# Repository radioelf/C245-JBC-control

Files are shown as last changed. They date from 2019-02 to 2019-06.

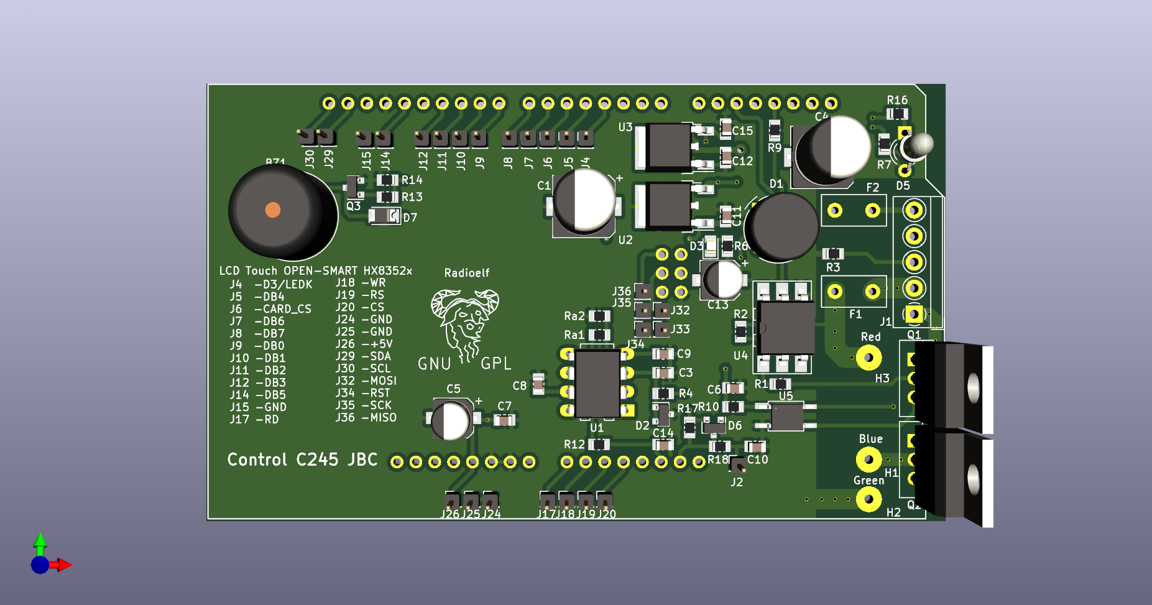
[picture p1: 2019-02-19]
cad/JBC_C245/jbc_245.png

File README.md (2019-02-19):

# C245 JBC control

 Harware y sofware para el control de soldadores JBC con puntas del tipo C245
 el  harware se ha realizado con KiCad y el sofware para un Arduino Mega.

Creative Commons License Disclaimer

UNLESS OTHERWISE MUTUALLY AGREED TO BY THE PARTIES IN WRITING, LICENSOR OFFERS THE WORK AS-IS AND MAKES NO REPRESENTATIONS OR WARRANTIES OF ANY KIND CONCERNING THE WORK, EXPRESS, IMPLIED, STATUTORY OR OTHERWISE, INCLUDING, WITHOUT LIMITATION, WARRANTIES OF TITLE, MERCHANTIBILITY, FITNESS FOR A PARTICULAR PURPOSE, NONINFRINGEMENT, OR THE ABSENCE OF LATENT OR OTHER DEFECTS, ACCURACY, OR THE PRESENCE OF ABSENCE OF ERRORS, WHETHER OR NOT DISCOVERABLE. SOME JURISDICTIONS DO NOT ALLOW THE EXCLUSION OF IMPLIED WARRANTIES, SO SUCH EXCLUSION MAY NOT APPLY TO YOU. EXCEPT TO THE EXTENT REQUIRED BY APPLICABLE LAW, IN NO EVENT WILL LICENSOR BE LIABLE TO YOU ON ANY LEGAL THEORY FOR ANY SPECIAL, INCIDENTAL, CONSEQUENTIAL, PUNITIVE OR EXEMPLARY DAMAGES ARISING OUT OF THIS LICENSE OR THE USE OF THE WORK, EVEN IF LICENSOR HAS BEEN ADVISED OF THE POSSIBILITY OF SUCH DAMAGES.

http://creativecommons.org/licenses/by-sa/3.0/

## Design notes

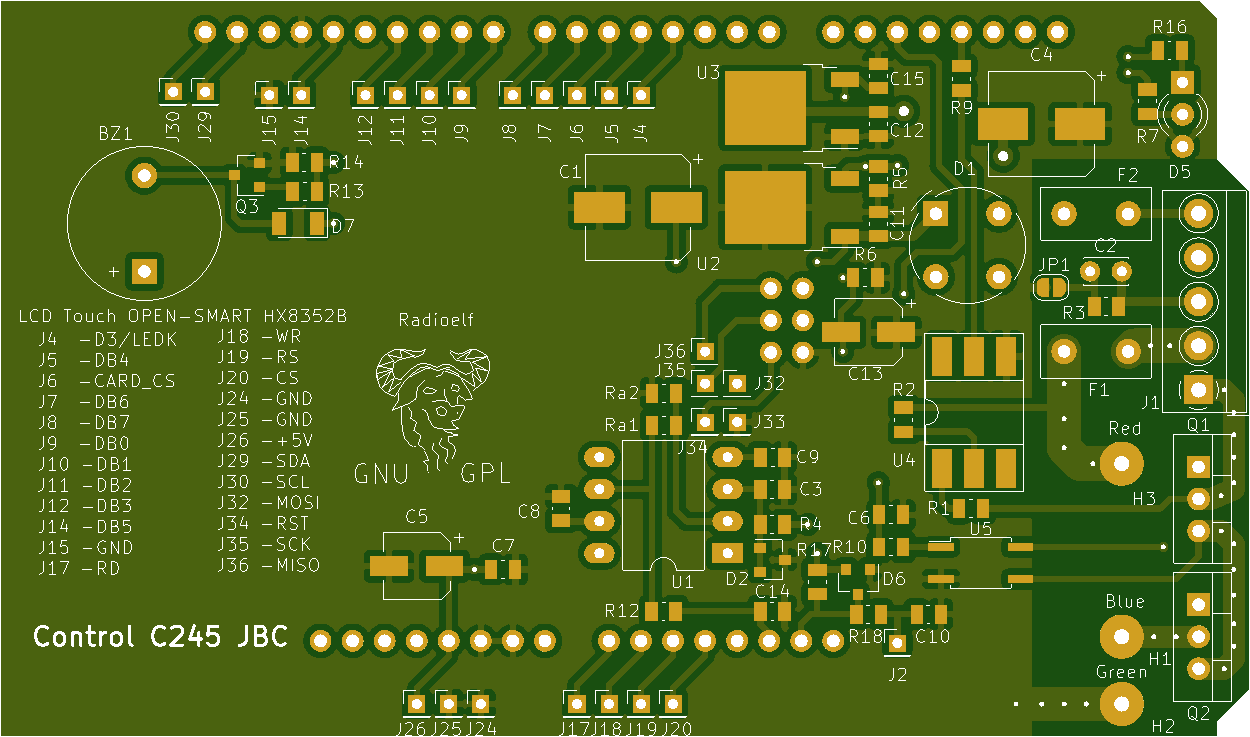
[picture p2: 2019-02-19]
cad/JBC_C245/c05b7eac-661d-4eba-980e-21c51f4449f4_1_0_1.png

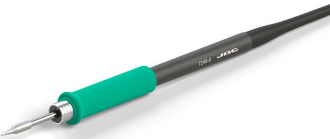
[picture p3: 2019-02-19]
sof/imagenes/jbc.png

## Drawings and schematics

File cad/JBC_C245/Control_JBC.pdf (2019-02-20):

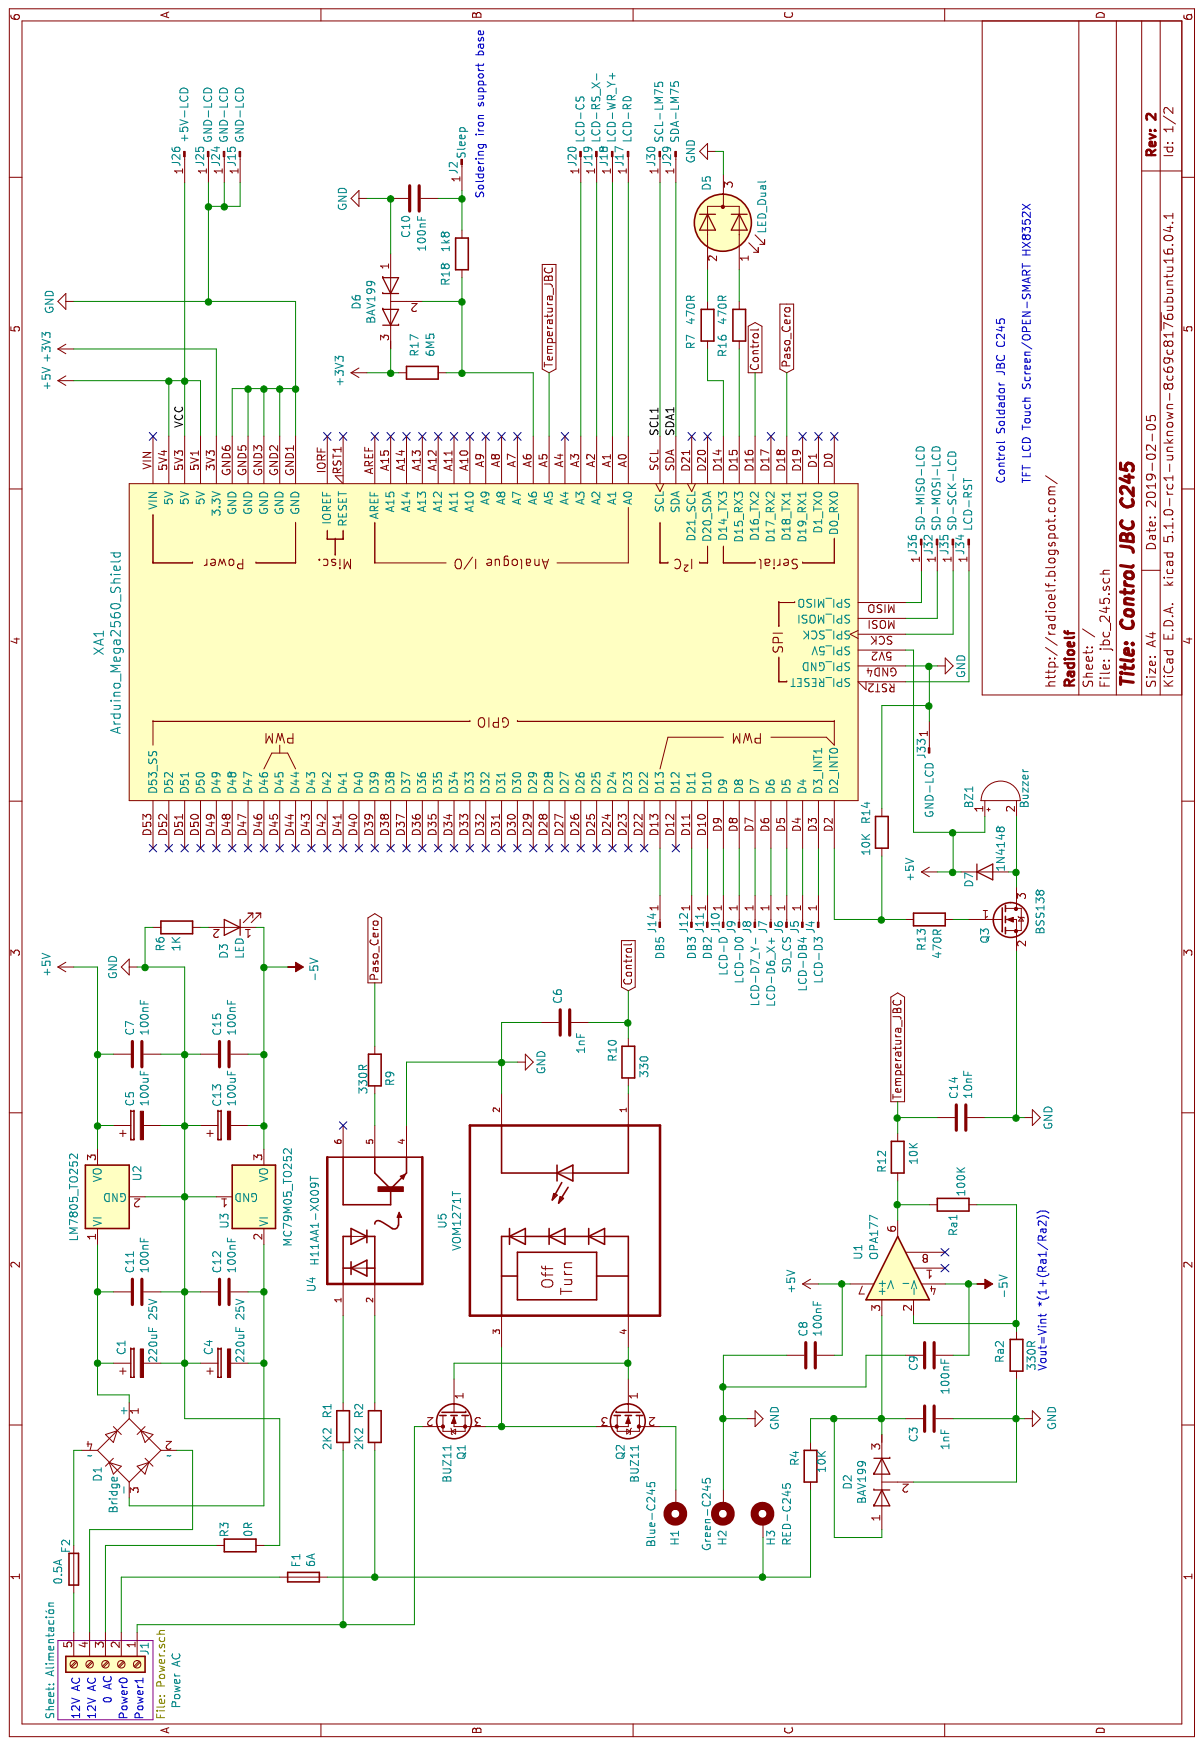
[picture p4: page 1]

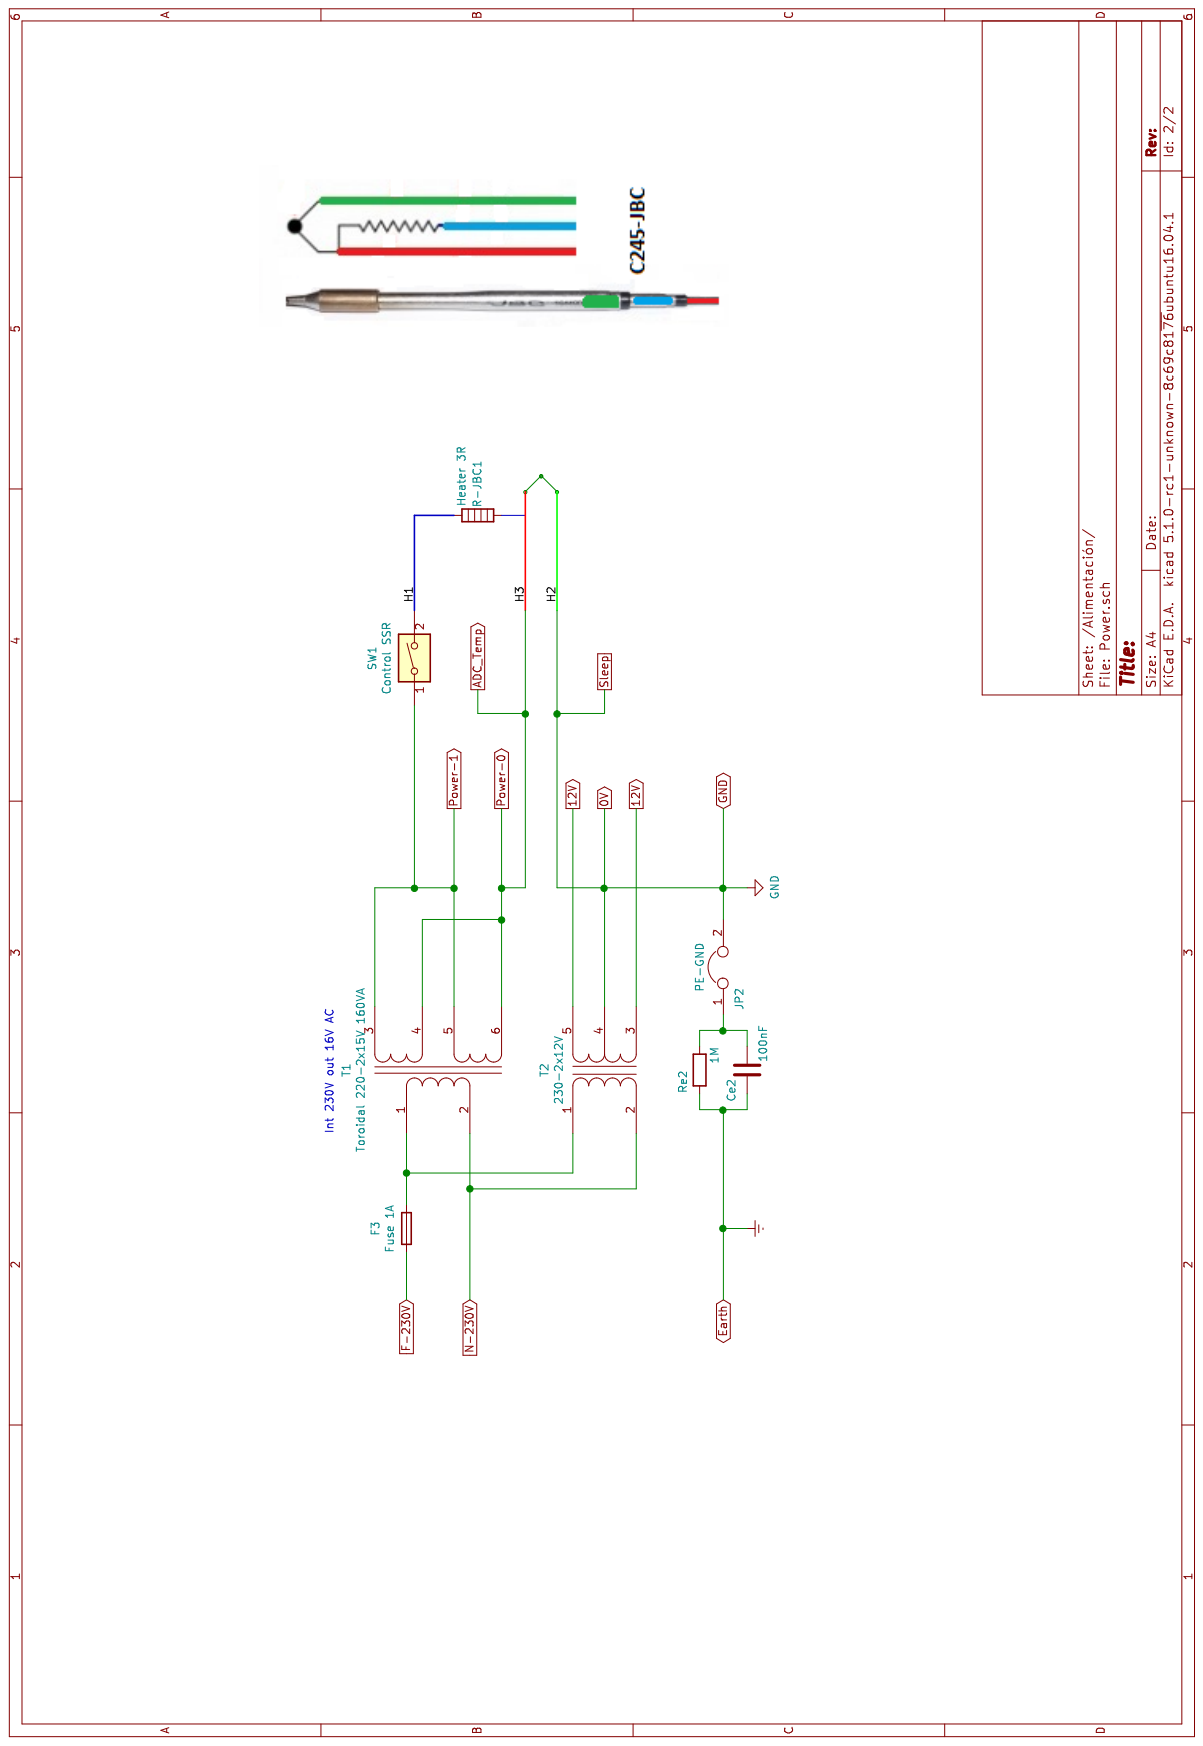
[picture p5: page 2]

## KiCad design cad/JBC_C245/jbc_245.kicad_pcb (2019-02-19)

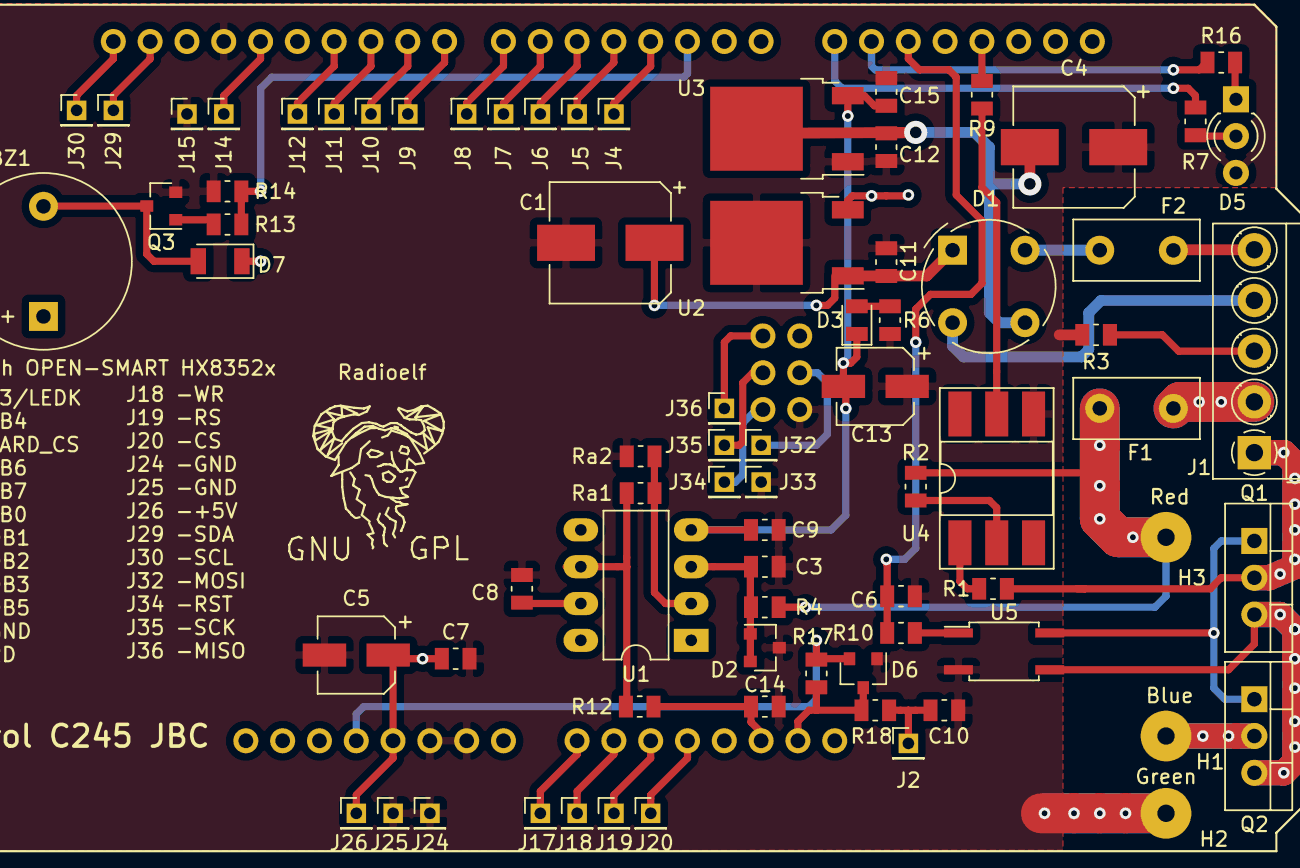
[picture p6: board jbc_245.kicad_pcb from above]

Board: 2 copper layers, 79 parts (0 on the bottom side), 54 nets.

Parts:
BZ1: Buzzer; Buzzer_12x9.5RM7.6
C1, C4: 220uF 25V; CP_Elec_8x10
C3, C6: 1nF; C_0805_2012Metric
C5, C13: 100uF; CP_Elec_5x4.5
C7, C8, C9, C10, C11, C12, C15: 100nF; C_0805_2012Metric
C14: 10nF; C_0805_2012Metric
D1: Bridge; Diode_Bridge_Round_D9.0mm
D2, D6: BAV199; D_SOT-23_BAV199
D3: LED; LED_0805_2012Metric
D5: LED_Dual; LED_D3.0mm-3
D7: 1N4148; D_1206_3216Metric
F1: 6A; Fuse_Littlefuse_395Series
F2: 0.5A; Fuse_Littlefuse_395Series
H1: Blue-C245; SolderWirePad_single_1-2mmDrill
H2: Green-C245; SolderWirePad_single_1-2mmDrill
H3: RED-C245; SolderWirePad_single_1-2mmDrill
J1: Power AC; TerminalBlock_MetzConnect_Type059_RT06305HBWC_1x05_P3.50mm_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
J2: Sleep; PinHeader_1x01_P2.00mm_Vertical
J4: LCD-D3; PinHeader_1x01_P2.00mm_Vertical
J5: LCD-DB4; PinHeader_1x01_P2.00mm_Vertical
J6: SD_CS; PinHeader_1x01_P2.00mm_Vertical
J7: LCD-D6_X+; PinHeader_1x01_P2.00mm_Vertical
J8: LCD-D7_Y-; PinHeader_1x01_P2.00mm_Vertical
J9: LCD-D0; PinHeader_1x01_P2.00mm_Vertical
J10: LCD-D; PinHeader_1x01_P2.00mm_Vertical
J11: DB2; PinHeader_1x01_P2.00mm_Vertical
J12: DB3; PinHeader_1x01_P2.00mm_Vertical
J14: DB5; PinHeader_1x01_P2.00mm_Vertical
J15, J24, J25, J33: GND-LCD; PinHeader_1x01_P2.00mm_Vertical
J17: LCD-RD; PinHeader_1x01_P2.00mm_Vertical
J18: LCD-WR_Y+; PinHeader_1x01_P2.00mm_Vertical
J19: LCD-RS_X-; PinHeader_1x01_P2.00mm_Vertical
J20: LCD-CS; PinHeader_1x01_P2.00mm_Vertical
J26: +5V-LCD; PinHeader_1x01_P2.00mm_Vertical
J29: SDA-LM75; PinHeader_1x01_P2.00mm_Vertical
J30: SCL-LM75; PinHeader_1x01_P2.00mm_Vertical
J32: SD-MOSI-LCD; PinHeader_1x01_P2.00mm_Vertical
J34: LCD-RST; PinHeader_1x01_P2.00mm_Vertical
J35: SD-SCK-LCD; PinHeader_1x01_P2.00mm_Vertical
J36: SD-MISO-LCD; PinHeader_1x01_P2.00mm_Vertical
Q1, Q2: BUZ11; TO-220-3_Vertical
Q3: BSS138; SOT-23
R1, R2: 2K2; R_0805_2012Metric
R3: 0R; R_0805_2012Metric
R4, R12, R14: 10K; R_0805_2012Metric
R6: 1K; R_0805_2012Metric
R7, R13, R16: 470R; R_0805_2012Metric
R9: 330R; R_0805_2012Metric
R10: 330; R_0805_2012Metric
R17: 6M5; R_0805_2012Metric
R18: 1k8; R_0805_2012Metric
Ra1: 100K; R_0805_2012Metric
Ra2: 330R; R_0805_2012Metric
Radioelf: Symbol_GNU-Logo_SilkscreenTop
U1: OPA177; DIP-8_W7.62mm_LongPads
U2: LM7805_TO252; TO-252-2
U3: MC79M05_TO252; TO-252-2
U4: H11AA1-X009T; DIP-6_W8.89mm_SMDSocket_LongPads
U5: VOM1271T; SO-4_4.4x3.6mm_P2.54mm
XA1: Arduino_Mega2560_Shield; Arduino_Mega2560_MOD

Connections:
0V: C1.2, C3.2, C4.1, C5.2, C6.1, C7.2, C8.1, C9.1, C10.2, C11.2, C12.1, C13.1, C14.2, C15.1, D2.2, D5.3, D6.1, H2.1, J15.1, J24.1, J25.1, J33.1, Q3.2, R3.2, R6.2, R14.1, Ra2.1, U2.2, U3.1, U4.4, U5.2, XA1.GND1, XA1.GND2, XA1.GND3, XA1.GND4
+3V3: D6.3, R17.1, XA1.3V3
+5V: BZ1.1, C5.1, C7.1, C8.2, D7.1, J26.1, U1.7, U2.3, XA1.5V1, XA1.5V2
-5V: C9.2, C13.2, C15.2, D3.1, U1.4, U3.3
Control: C6.2, R10.1, XA1.D16
unnamed: BZ1.2, D7.2, Q3.3
unnamed: C1.1, C11.1, D1.1, U2.1
unnamed: C3.1, D2.1, D2.3, R4.1, U1.3
unnamed: C10.1, J2.1, R18.2
unnamed: C4.2, C12.2, D1.3, U3.2
unnamed: D1.2, J1.4
unnamed: D1.4, F2.1
unnamed: D3.2, R6.1
unnamed: D5.1, R16.2
unnamed: D5.2, R7.2
unnamed: D6.2, R17.2, R18.1, XA1.A6
unnamed: F1.1, J1.2
unnamed: F1.2, H3.1, R2.2, R4.2
unnamed: F2.2, J1.5
unnamed: H1.1, Q2.2
unnamed: J1.1, Q1.2, R1.2
unnamed: J1.3, R3.1
unnamed: J4.1, XA1.D3
unnamed: J5.1, XA1.D4
unnamed: J6.1, XA1.D5
unnamed: J7.1, XA1.D6
unnamed: J8.1, XA1.D7
unnamed: J9.1, XA1.D8
unnamed: J10.1, XA1.D9
unnamed: J11.1, XA1.D10
unnamed: J12.1, XA1.D11
unnamed: J14.1, XA1.D13
unnamed: J17.1, XA1.A0
unnamed: J18.1, XA1.A1
unnamed: J19.1, XA1.A2
unnamed: J20.1, XA1.A3
unnamed: J32.1, XA1.MOSI
unnamed: J34.1, XA1.RST2
unnamed: J35.1, XA1.SCK
unnamed: J36.1, XA1.MISO
unnamed: Q1.1, Q2.1, U5.4
unnamed: Q1.3, Q2.3, U5.3
unnamed: Q3.1, R13.2
unnamed: R1.1, U4.1
unnamed: R2.1, U4.2
unnamed: R7.1, XA1.D14
unnamed: R9.1, U4.5
unnamed: R10.2, U5.1
unnamed: R12.2, Ra1.1, U1.6
unnamed: R13.1, R14.2, XA1.D2
unnamed: R16.1, XA1.D15
unnamed: Ra1.2, Ra2.2, U1.2
Paso_Cero: R9.2, XA1.D18
Temperatura_JBC: C14.1, R12.1, XA1.A5

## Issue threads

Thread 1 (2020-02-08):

Good toy

Genxgen, 2020-02-08:
Good toy , if the function 'current limit'  available will be better, that can  avoid JBC heater be damaged by over current.

JHS1211, 2020-06-18:
您好，您的这个JBC控制器很好，我制作了一个，但是，显示屏不正常，现在HX8352A的显示屏很少，而且与您的可能不是一样的，我用的自己制作的PCB，用的是44P的HX8352A  262K的显示屏，但是显示的意思不正常，缺少高8位的颜色，用的是2个74C245D,我用的这个屏是不是不对？您可否把程序改成262K的使用的程序？非常感谢。

JHS1211, 2020-06-18:
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

Closed 2020-06-19.

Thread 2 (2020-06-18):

C245-JBC-控制

JHS1211, 2020-06-18:

JHS1211, 2020-06-18:
> Hello, you JBC controller is very good, I made a, however, showed abnormal, HX8352A shows very little now, and you may not be the same, I use a pcset, using the 44 p HX352A 262 k, but the color is not normal, not high 8-bit color, there should be no red, I use low 8 drive, because of high eight white, 4 c, this is my screen? Program can be changed to 262 k application? Thank you very much.

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

radioelf, 2020-06-18:
Hi. I don't have any ILI9327 screen to test, you can try some examples from the library?, to validate the screen..

JHS1211, 2020-06-18:
Hello, I didn't find the HX8352A you welding units use the LCD module, only found 16 HX8352A LCD module, I use this screen to change to use two 74 hc245d PCB, but only sent to the first picture shows the color, (pictured), I don't know what reason be? This screen is 262 k, your screen is 65 k? Display is not normal and this matter? I don't really understand this, thank you very much!

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

JHS1211, 2020-06-18:
这是我自己画的PCB，不知有什么问题？希望您能给与指教。感谢！
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
[TM032LDH05.pdf](https://github.com/radioelf/C245-JBC-control/files/4799429/TM032LDH05.pdf)

radioelf, 2020-06-18:
HI, try to validate your lcd with some simple example from the library, I don't have  ILI9327, to check the problem.

https://github.com/prenticedavid/MCUFRIEND_kbv/tree/master/examples

JHS1211, 2020-06-18:
[TM032LDH05.pdf](https://github.com/radioelf/C245-JBC-control/files/4799479/TM032LDH05.pdf)

JHS1211, 2020-06-18:
谢谢您的指教，这个屏可以用在您的焊台上吗？

radioelf, 2020-06-18:
Now I have no screen to test,,,

JHS1211, 2020-06-18:
You this soldering station using HX8352A LCD module where I can buy? Thank you very much!

radioelf, 2020-06-18:
Yes, But you can modify/settings the library to use another LCD.

https://github.com/prenticedavid/MCUFRIEND_kbv/blob/master/extras/mcufriend_how_to.txt

JHS1211, 2020-06-18:
Thank you, I was too stupid, don. Don't change program, have LCD screen assembly line still available.
If you can buy with LCD modules to assemble.

JHS1211, 2020-07-01:
Hello, I ask, do you have 3.2 240 x400 HA8352A LCD module specifications and materials? Can you share? Thank you very much!

Closed 2020-06-19.

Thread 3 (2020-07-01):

C245-JBC

JHS1211, 2020-07-01:
Hello, I ask, do you have 3.2 240 x400 HA8352A LCD module specifications and materials? Can you share? Thank you very much!

radioelf, 2020-07-01:
Hi. you can look https://www.youtube.com/watch?v=2_4dZHR1aU0 and https://drive.google.com/drive/folders/1C7fec55cgBTltYG_zs_t0RN0wg24lncN , I don't have HA8352A LCD...

JHS1211, 2020-09-23:
Hello, I made your soldering station, but show the temperature there is a problem, in the program, the highest temperature setting dormancy temperature and set temperature show 65535, cannot adjust, what's the problem? Look forward to your comments, thank you.

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

radioelf, 2020-09-24:
Hi. temperature maximum, standby and run are of type uint16_t (0-65535), in lines 68, 69 and 71 of the code, are the initial values (default):
uint16_t Temp_Max[3] = {450, 450, 450};                           // temperatura máxima 450 °C M1, M2, M3
uint16_t Temp_Standby[3] = {180, 200, 225};                    // temperatura en modo standby M1, M2, M3
uint16_t Ini_Temp[3] = {340, 350 , 375};                            // temperatura inicial de trabajo M1, M2, M3
minimum temperature is correct (type uint8_t), this makes me think of a mistake when reading the EEPROM, is using an arduino Mega?

JHS1211, 2020-09-24:
Yes MEGA2560

发自我的iPhone

------------------ Original ------------------
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

JHS1211, 2020-09-24:
Hello, thank you for your reply, I'm very sorry, I'm not to modify the code, you can block the EEPROM to modify good, send me a, can? Various temperature setting code value is good for you, thank you very much!

radioelf, 2020-09-24:
Hi.
I don't have much time for testing, I have made some small changes, can you try?
https://www.dropbox.com/sh/hsiqosuhe77o3pt/AADwNDIiTPp5T8JGyA_KDvUna?dl=0

JHS1211, 2020-09-24:
hello
I did a test, it is white, my screen drive is ILI9327, might be driving it?

radioelf, 2020-09-24:
Hello.
I don't have a ILI9327 screen (for testing), you can try to program with its previous version, if the EEPROM was programmed correctly (with the latest version) it could work....

JHS1211, 2020-09-24:
hello
I won't be programming, you block the EEPROM compile best good, send me a copy.
ILI9327 yourself, can I?

JHS1211, 2020-09-24:
Why can only cool when welding machine heating? Warming up arrow touch, but cool.
Is at work can not raise the temperature?

radioelf, 2020-09-24:
Block the EEPROM, means much code modification; you may NOT increase the temperature for safety reasons, as the values are out of range....

JHS1211, 2020-09-24:
Both up and down arrow is to adjust temperature? Only can regulate the temperature of a standby?
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

JHS1211, 2020-09-24:
Why can't work only the cooling up? Is this normal?
[IMG_3034.zip](https://github.com/radioelf/C245-JBC-control/files/5275645/IMG_3034.zip)

radioelf, 2020-09-24:
You can see a video of the operation https://www.youtube.com/watch?v=qMxd-N4Ooyk ; in the picture is NOT in the mode  standby; in the video it seems that the calibration of the keyboard-screen is not working properly, it is necessary to compile the code for your screen

JHS1211, 2020-09-24:
Yes, in the video, don't have the operation, you really need to screen the compiled code, the soldering station how beautiful ah, you should improve his, otherwise it's too bad.
Again, the output of the MOS tube is too hot, hot, shouldn't be so hot, what's the solution?

radioelf, 2020-09-24:
My station is working fine, and the code is free on github for anyone who wants to use/improve it, i don't have time to make changes now...

JHS1211, 2020-09-24:
Your workstation using AC16V AC24V can use?

radioelf, 2020-09-24:
Toroidal transformer 220-2x15V 160VA (if it is different in your station in necessary to compile code with new PID values.)
more information (in Spanish) http://radioelf.blogspot.com/2019/02/control-soldador-jbc-c245-finalizado.html
http://radioelf.blogspot.com/2019/02/calculos-termopar-c245-jbc.html
http://radioelf.blogspot.com/2019/02/obteccion-valores-pid-jbc-c-245.html
http://radioelf.blogspot.com/2019/02/control-soldador-jbc-c-245.html
and https://github.com/radioelf/C245-JBC-control/blob/master/cad/JBC_C245/Control_JBC.pdf

Closed 2020-09-26.

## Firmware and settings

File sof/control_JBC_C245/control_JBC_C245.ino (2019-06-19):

/*
   Control para soldadores JBC C245, para arduino Mega, TFT HX8352A [OPEN-SMART]  

  JBC C245 tiene un termopar desconocido, según la calibración realizada con una sonda externa
  colocada sobre la punta del soldador, he obtenido el factor de 0.4693221 para usar en la lectura ADC
  con Vcc de 4.9V, el valor medido de Ra1 de 99959.0 ohm y Ra2 de 329.52 ohm.
  
  -el amplificado operacional tiene una ganancia de 1+(Ra1/Ra2) -> 1 + (99959.0 / 329.52)->304.347293032
  -la precisión para el conversor ADC (10 bits) Vcc/1024 (1023 escalones de ~4.88mV)
  -calculo tensión entrada ADC del arduino mega V = (ADC) * Vcc / 1024 el valor ADC corresponde a un
   intervalo de tensión, (de 0 a ~4.88mV-> ADC =0, de ~4.89mV a ~9.76mV-> ADC =1... de 4.99V a 5V-> ADC =1023) 
  -la temperatura en grados centígrados para 1mV es de unos ~29.85°C (calibración a 300°C)

  Calculo para obtener el factor ADC: 
    factor =temperatura por 1mV/((0.001 * (1 + (Ra1/ Ra2)))/(Vcc /1024.0))
    
  En algunos foros se comenta que el termopar es de tipo N que entrega 1mV a 37.63°C
         37.63/((0.001 * (1 + (99959.0 / 329.52)))/(5 / 1024.0)) =0.6037189703392771
  En algunos foros se comenta que el termopar entrega 1mV a 43.5°C
         43.5/((0.001 * (1 + (99959.0 / 329.52)))/(5 / 1024.0)) =0.6978946375168363

  Se realiza una calibración a 300 grados y obtenemos un valor de ~29.85°C para 1mV
  calculo para Vcc a 4.9V-> 29.85/((0.001 * (1 + (99959.0 / 329.52)))/(4.9 / 1024.0)) =0.4693221110639084
  factor = 0.4693221 (arduino mega solo utiliza 7 decimales)

  Valores PID:
  KP: si se incrementa, más fuerte es el control.
  KI: si se decrementa (0 =OFF), más rápidamente reaccionará el controlador a los cambios, pero
      mayor es el riesgo de oscilaciones.
  KD: cuanto mayor es el valor, más amortigua las oscilaciones el controlador (pero el rendimiento
      puede verse afectado)

     Radioelf - Febrero 2019
  http://radioelf.blogspot.com.es/

  Copyright (c) 2019 Radioelf.  All rights reserved.

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
*/
#define Version "Control JBC V 0.0.4"                             
const String Fecha = String(__DATE__);                            // obtenemos la fecha
//#define Debug                                                   // ON-OFF debugger serial

#include <Wire.h>
#include <LM75.h>                                                 // https://github.com/thefekete/LM75
#include <EEPROM.h>
#include <PID_v1.h>                                               // https://github.com/br3ttb/Arduino-PID-Library/ (MOD.)
// SD
//#include <SPI.h>
//#include <SD.h>

#define SET(port,bit) (port|=(1<<bit))                            // macro para pasar a 1 el bit indicado
#define CLR(port,bit) (port&=(~(1<<bit)))                         // macro para pasar a 0 el bit indicado

// Memorias de 1 a la 3 (defecto)
uint8_t SelecMem = 0;
uint8_t  Config = B10000111;                                      // mascara de configuración
uint16_t Temp_Max[3] = {450, 450, 450};                           // temperatura máxima 450 °C M1, M2, M3
uint16_t Temp_Standby[3] = {180, 200, 225};                       // temperatura en modo standby M1, M2, M3
uint8_t  Temp_Min[3] = {160, 160, 160};                           // temperatura minina (0-255) M1, M2, M3
uint16_t Ini_Temp[3] = {340, 350 , 375};                          // temperatura inicial de trabajo M1, M2, M3
//Valores para proporcional, derivada e integral
double Kp = 2238, Ki = 14, Kd = 47.5;
double EsperaPID = 50, InputTemp = 0.0, Setpoint = Ini_Temp[0];

const double Factor = 0.4693221;								                  // factor calculado para 29.85 grados centígrados a 1mV

volatile double Temp = 0.0;
volatile uint8_t ContaISR = 0;
volatile uint16_t ADC_ISR = 0, ReposoADC;
double Tem_lm75, Tem_comp;

#define Buzzer_pin 2                                                // Pin zumbador      
//#define LCD_Ledk_pin 3
#define PasoCero_pin 18                                           	// Pin 46 ATMEGA2560-> PD3
#define Control_pin 16                                            	// Pin 13 ATMEGA2560-> PH1
#define LedRD_pin 14                                              	// led rojo
#define LedGN_pin 15                                              	// led verde
#define TC_pin A5                                                 	// ADC termopar JBC
#define Reposo_Pin A6                                             	// ADC reposo

#include "bitmap.h"
#include "eeprom.h"
#include "tft.h"

// InputTemp entrada de la temperatura del soldador
// EsperaPID valor a enviar Timer1 tras el paso por cero
// Setpoint valor de la temperatura deseada
// DIRECT al disminuir el valor se disminuye la temperatura (tiempo en ON)
// REVERSE al disminuir el valor se aumenta la temperatura (tiempo en OFF)
PID myPID(&InputTemp, &EsperaPID, &Setpoint, Kp, Ki, Kd, DIRECT);

//********************************************************************************************
// ISR por paso por cero (10ms->50hz) leemos la entrada analógica, obtenemos el valor del
// periodo de marcha e iniciamos el timer 1
//--------------------------------------------------------------------------------------------
void PasoCero_ISR() {
  if  (PINH & (1 << PH1)) {                                         // si el pin 16 se encuentra activo
    CLR(PORTH, PH1);
    return;
  }
  ADC_ISR = analogRead(TC_pin);
  Temp = InputTemp = (ADC_ISR * Factor) + Tem_comp;
  if (Temp - 5.0 < Setpoint) SET(PORTH, PH1);                       // ON pin 16 control si temperatura es < de setpoin+5grados
  if (Setpoint > Temp + 50.0 )                                      // si la diferencia es mayor de 50 grados
    EsperaPID = 19000;                                              // pulso ON de 9,500ms, OFF 500us
  else
    myPID.Compute(1);                                               // EsperaPID toma el valor del calculo PID
  TCNT1 = 0;                                                     	  // contador a 0
  OCR1A = uint16_t (EsperaPID);                                   	// pulso de (EsperaPID*0,5us)-> de 25us a 9025us
  TCCR1B |= _BV(CS11);                                            	// ON Timer 1, ~0,5uS pre-escaler a 8
  TIMSK1 |= _BV(OCIE1A);                                           	// RUN ISR comparador
}
//********************************************************************************************
// ISR comparador timer 1, se para la salida hasta el próximo paso por cero (modo PID DIRECT)
// cada 10 ciclos leemos la entrada analógica de soldador en reposo
//--------------------------------------------------------------------------------------------
ISR(TIMER1_COMPA_vect) {
  CLR(PORTH, PH1);                                                	// paramos señal de control
  TCCR1B &= ~_BV(CS11);                                           	// paramos timer1
  TIMSK1 &= ~_BV(OCIE1A);                                           // STOP ISR comparador
  if (++ContaISR == 10) {
    ReposoADC = analogRead(Reposo_Pin);                           	// ~25us-9ms después de leer TC_pin->A5
    ContaISR = 0;
  }
}
//********************************************************************************************
// ISR comparador timer 5, paramos timer 5 y off buzzer
//--------------------------------------------------------------------------------------------
ISR(TIMER5_COMPA_vect) {
  CLR(PORTE, PE4);
  TCCR5B = 0;                                                       // off timer 5
  TIMSK5 &= ~_BV(OCIE5A);                                           // STOP ISR comparador
}
//********************************************************************************************
// Configuración
//--------------------------------------------------------------------------------------------
void setup() {
  pinMode(TC_pin, INPUT);
  pinMode(Reposo_Pin, INPUT);
  pinMode(PasoCero_pin, INPUT_PULLUP);
  pinMode(Control_pin, OUTPUT);
  pinMode(LedRD_pin, OUTPUT);
  pinMode(LedGN_pin, OUTPUT);
  pinMode(Buzzer_pin, OUTPUT);
  pinMode(LCD_Ledk_pin, OUTPUT);
  digitalWrite(Control_pin, LOW);                                   // calentamiento soldador parado
  digitalWrite(LedRD_pin, HIGH);
  digitalWrite(LedGN_pin, HIGH);                                  	// led en naranja (rojo+verde)
  digitalWrite(Buzzer_pin, LOW);                                    // zumbador parado
  digitalWrite(LCD_Ledk_pin, LOW);                                  // retro-iluminación pantalla LCD OFF
#ifdef Debug
  Serial.begin(115200);
#endif
  Wire.setClock(400000);                                          	// 400kHz I2C clock.
  Wire.begin();

  //El preescaler ADC por defecto 128->16MHz/128 = 125 KHz, 13.5 ciclos cada muestra, sampling rate 125/13.5 =9.2Khz->108.7uS
  // preescale mínimo recomendado es de 16->1Mhz, 16MHz/16 =1Mhz, sampling rate 1000/13.5 =74Khz->13.5uS
  ADCSRA |= _BV(ADPS2);                                           	// bit 2 registro ADCSRA a 1
  ADCSRA &= ~_BV(ADPS1);                                          	// bit 1 registro ADCSRA a 0
  ADCSRA &= ~_BV(ADPS0);                                          	// bit 0 registro ADCSRA a 0

  //for (uint8_t x = 0; x < 16; x++) {EepromTx(x);}
  for (uint8_t x = 0; x < 4; x++) {
    EepromRx(x);                                                  	// leemos la configuración de la EEPROM de la posición 0 a la 3
  }
  BuzzerOnOFF = bitRead(Config, 0);                               	// leemos el estado del bit 0 (memoria 1)

  myPID.SetMode(AUTOMATIC);                                       	// enciende el PID
  myPID.SetOutputLimits(50, 18050);                               	// limites  de 50 a 18050, pulso de ~25us-9ms
  myPID.SetSampleTime(10);                                        	// se llama a Compute() cada 10 ms

  if (analogRead(Reposo_Pin) > 100) {
    Setpoint = Ini_Temp[0];
    ReposoMod = 0;
  } else {
    Setpoint = Temp_Standby[0];
  }

  Tem_lm75 = sensor.temp();                                       	// obtenemos la temperatura de la PCB
  Tem_comp = Tem_lm75;                                              // al arrancar es la misma que la del ambiente (union fria)
  InputTemp = Tem_lm75;                                             // la temperatura inicial es la de la PCB

  IniTFT (Setpoint, InputTemp, 0);                                  // inicializamos LCD
  digitalWrite(Buzzer_pin, HIGH);
  if (BuzzerOnOFF == 1) {
    DelayMs (50);
    digitalWrite(Buzzer_pin, LOW);
    DelayMs (100);
    digitalWrite(Buzzer_pin, HIGH);
    DelayMs (50);
  } else {
    DelayMs (50);
  }
  digitalWrite(Buzzer_pin, LOW);
  digitalWrite(LedRD_pin, LOW);
  digitalWrite(LedGN_pin, LOW);
  noInterrupts();
  // Config. pre-escaler a 8 bit, modo CTC, Timer 1 OFF (pre-escaler CS10, CS11 y CS12 a 0)
  TCCR1A = 0;
  TCCR1B = 0;
  TCCR1B |= _BV(WGM12);                                             // modo CTC, bit WGM12 a 1
  TCCR1B |= _BV(CS11);                                              // Timer 1 ON, pre-escaler a 8->0,5uS, bit CS11 a 1
  TCNT1 = 0;                                                        // contador a 0
  OCR1A = 0;                                                        // comparador a 0
  //TIMSK1 |= _BV(OCIE1A);                                          // ON ISR comparador, bit1 OCIE1A del registro TIMSK1 a 1
  TIMSK1 &= ~_BV(OCIE1A);                                         	// STOP ISR comparador, bit1 OCIE1A del registro TIMSK1 a 0
  // configuramos Timer 5 STOP
  TCCR5A = 0;
  TCCR5B = 0;                                                       // timer 5 OFF
  OCR5A = 0;                                                        // comparador a 0
  TIMSK5 &= ~_BV(OCIE5A);                                           // STOP ISR comparador
  interrupts();
  Buzzer(0);
  attachInterrupt(digitalPinToInterrupt(PasoCero_pin), PasoCero_ISR, RISING); // flanco de subida de LOW a HIGH
  DelayMs (55);                                                     // nos aseguramos de realizar varias lecturas (ISR)
}

uint8_t SelecZona = 0, LedRun = 0, Pulsacion = 0, PorceAnt = 0, Media = 0, ErrorISR = 0;
uint8_t RepTra = 0, Ciclo = 0, Error = 0, OK_Temp = 1, STOP = 0, CicloLoop = 0;
int8_t MemISR = -1;
uint16_t  MediaTemp = 0;
uint32_t Perido_Reposo = 0;
double Tem_PCB, TempAnt = 0.0;
//********************************************************************************************
// Principal
//--------------------------------------------------------------------------------------------
void loop() {
  DelayMs (5);
  if (STOP == 0) {
    actualiza (CicloLoop++);                                       	// como mínimo cada 5ms actualizamos
  } else {
    if (++STOP == 11) {
      uint8_t Parpadeo = !digitalRead(LedRD_pin);
      digitalWrite(LedRD_pin, Parpadeo);
      digitalWrite(LedGN_pin, Parpadeo);
      STOP = 1;
    }
    DelayMs (45);
    if (TFTpuntero()) {                                             // si nos encontramos en STOP
      if (TFTzona(0) == 7) {                                       	// pulsado botón ON-OFF?
        OffOn_JBC(1);                                               // ON control soldador
        Buzzer(50);
        Perido_Reposo = millis();
      } else {                                                      // pulsación NO valida
        if (BuzzerOnOFF == 1) {
          digitalWrite(Buzzer_pin, HIGH);
          DelayMs (250);
          digitalWrite(Buzzer_pin, LOW);
        }
      }
    }
  }
}
//********************************************************************************************
// Actualización, una opción en cada paso por cero (10ms a 50Hz)
//--------------------------------------------------------------------------------------------
void actualiza(uint8_t opcion) {
  switch (opcion) {
    case 1:                                                         // 265us
      Pulsacion = TFTpuntero();                                     // comprobamos si se esta pulsando en la pantalla
      break;
    case 2:                                                         // 4us
      if (Pulsacion)                                                // comprobamos si se pulso una zona valida
        SelecZona = TFTzona(0);                                     // obtenemos la zona pulsada para su gestión
      break;
    case 3:                                                         // 4us
      if (SelecZona) {                                              // zonas de 1 al 8
        Buzzer(50);                                                 // indicamos pulsación en zona valida
        if (SelecZona  == 8) {                                      // inicializar periodo de reposo
          Perido_Reposo = millis();
          SelecZona = 0;
          break;
        }
        Boton(SelecZona);                                           // gestión botón pulsado
        DelayMs(50);
        while (TFTpuntero()) {
          Boton(TFTzona(0));
          DelayMs(150);
        }
      }
      break;
    case 4:                                                         // 24us
      if (++Ciclo == 10) {                                          // leemos la temperatura de la PCB
        Tem_PCB = sensor.temp();
        Ciclo = 0;
        if (Tem_lm75 != Tem_PCB) {                                  // si la temperatura es distinta a la mostrada anteriormente en pantalla
          TFTLm75(Tem_PCB);                                         // actualizamos nueva temperatura en pantalla
          Tem_lm75 = Tem_PCB;
        }
      } else {
        RepTra = Reposo();                                          // comprobamos si tenemos el soldador en reposo
        if (ModoTrab != RepTra && ModoTrab != 0) {                  // si tenemos cambio de estado y no estamos en apagado
          noInterrupts();
          RepTra == 1 ? Setpoint = Ini_Temp[SelecMem] : Setpoint = Temp_Standby[SelecMem];
          int16_t IntSetPoint = Setpoint;
          interrupts();
          TFTUpdateSet(IntSetPoint);
          TFTEsperaOnOff();                                        	// actualizamos estado botón ON/OFF en TFT
          ModoTrab = RepTra;
          RepTra == 2 ? OK_Temp = 0 : OK_Temp = RepTra;
        }
      }
      break;
    case 5:
      if (Ciclo == 5) {
        int16_t TempMedia = round(MediaTemp / Media);				        // 85ms
        MediaTemp = 0;
        Media = 0;
        if (TempMedia != TempAnt && Error == 0) {                  	// si tenemos un valor distinto actualizamos en TFT
          TFTColorTemp(Setpoint, Temp);
          TempAnt = TempMedia;
        }
      } else {
        if (Temp < (Temp_Max[SelecMem] + 25)) {
          MediaTemp += uint16_t (Temp);
          Media++;
        }
        if (Setpoint <= Temp && OK_Temp != 0 ) {
          Buzzer(50);
          OK_Temp = 0;
        }
      }
      break;
    case 6:                                                         // 56us
      Led_status ();                                                // leds
      if (Ciclo % 3 == 0) {
        if (ContaISR == MemISR) {
          ErrorISR++;
        } else {
          MemISR = ContaISR;
          ErrorISR = 0;
        }
        if ((Temp > 460) || (Temp <= Tem_comp) || (ErrorISR > 5) ) { // seguridad
          noInterrupts();
          uint16_t AdcIsr = ADC_ISR;
          interrupts();
          if ((AdcIsr > 800 || AdcIsr == 0) && Error >= 2) Error = 99;// sin punta del soldador
          if (ErrorISR > 2) Error = 199;                            // error en ISR
          if (++Error > 9) {
            OffOn_JBC(0);                                           // OFF control soldador
            TFTError(Error);                                        // si es un cambio de punta soldador (la función retorna)
            CambTool();                                             // cambio de punta
            Error = 0;
            ErrorISR = 0;
          }
        } else {
          Error = 0;
        }
      }
      if (Ciclo % 2 == 0) {
        uint8_t Porce = Porcentaje();                               // obtenemos el porcentaje de trabajo
        if (Porce != PorceAnt) {                                    // si es distinto actualizamos nuevo valor en TFT
          TFTPorcentaje(Porce);
          PorceAnt = Porce;
        }
      }
      CicloLoop = 0;
      break;
  }
}
//********************************************************************************************
// Gestión del botón pulsado en pantalla TFT
//--------------------------------------------------------------------------------------------
void Boton(uint8_t Selec) {
  uint16_t IntSetPoint;
  SelecZona = 0;
  switch (Selec) {
    case 1:                                                         // selección a acceso a configuración
      OffOn_JBC(0);                                                 // OFF control soldador
      TFTConfigJBC();
      break;
    case 2:                                                         // selección memoria 1
      if (ModoTrab == 0) {                                          // si estamos es OFF salimos
        Buzzer(250);
        break;
      }
      TFTMemoria(1);
      noInterrupts();
      ModoTrab == 1 ? Setpoint = double (Ini_Temp[SelecMem]) : Setpoint = double (Temp_Standby[SelecMem]);
      IntSetPoint = uint16_t (Setpoint);
      interrupts();
      TFTUpdateSet(IntSetPoint);
      break;
    case 3:                                                         // selección memoria 2
      if (ModoTrab == 0) {                                          // si estamos es OFF salimos
        Buzzer(250);
        break;
      }
      TFTMemoria(2);
      noInterrupts();
      ModoTrab == 1 ? Setpoint = double (Ini_Temp[SelecMem]) : Setpoint = double (Temp_Standby[SelecMem]);
      IntSetPoint = uint16_t (Setpoint);
      interrupts();
      TFTUpdateSet(IntSetPoint);
      break;
    case 4:                                                         // selección memoria 3
      if (ModoTrab == 0) {                                          // si estamos es OFF salimos
        Buzzer(250);
        break;
      }
      TFTMemoria(3);
      noInterrupts();
      ModoTrab == 1 ? Setpoint = double (Ini_Temp[SelecMem]) : Setpoint = double (Temp_Standby[SelecMem]);
      IntSetPoint = uint16_t (Setpoint);
      interrupts();
      TFTUpdateSet(IntSetPoint);
      break;
    case 5:                                                         // selección incremento/decremento setpoint
      if (ModoTrab == 0) {                                          // si estamos es OFF salimos
        Buzzer(250);
        break;
      }
      if (Setpoint >= Temp_Max[SelecMem]) break;                    // limite superior?
      noInterrupts();
      ModoTrab == 1 ? Setpoint = ++InputTemp : Setpoint = double (++Temp_Standby[SelecMem]);
      IntSetPoint = uint16_t (Setpoint);
      interrupts();
      TFTUpdateSet(IntSetPoint);
      break;
    case 6:
      if (Setpoint <= Temp_Min[SelecMem]) break;                    // limite inferior?
      noInterrupts();
      ModoTrab == 1 ? Setpoint = --InputTemp : Setpoint = double (--Temp_Standby[SelecMem]);
      IntSetPoint = uint16_t (Setpoint);
      interrupts();
      TFTUpdateSet(IntSetPoint);
      break;
    case 7:                                                         // pulsación botón ON-OFF
      Buzzer(50);
      OffOn_JBC(TFTOnOff(1));                                       // mostramos el estado de la pulsación del botón de ON-OFF
      break;
    case 8:                                                         // pulsación botón espera
      Perido_Reposo = millis();                                     // iniciamos periodo reposo
      Buzzer(50);
      break;
  }
}
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

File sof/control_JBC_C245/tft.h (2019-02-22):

/*
  pines TFT LCD Touch Screen/OPEN-SMART HX8352A 240x400:
  +5V- 150 mA
  GND-
  A0 - LCD-RD lectura datos
  A1 - LCD-WR escritura datos + pantalla táctil digital Y+ horizontal
  A2 - LCD-RS registro instrucciones/datos + pantalla táctil digital X+ vertical
  A3 - LCD-CS selección lcd
  3  - D3 retro iluminación (no 5-3v3)
  4  - LCD-DB4 datos bit 4
  5  - SD_CS selección tarjeta
  6  - LCD_D6 datos bit 6 + pantalla táctil digital X- horizontal
  7  - LCD_D7 datos bit 7 + pantalla táctil digital Y- vertical
  8  - LCD-D0 datos bit 0
  9  - LCD-D1 datos bit 1
  10 - DB2 datos bit 2
  11 - DB3 datos bit 3
  13 - DB5 datos bit 5
  SDA1 -SDA no 5<->3v3
  SCL1 -SCL no 5->3v3
  conector central SPI para SD + LCD_RST
  VCC->5V
  MOSI
  GND
  LCD_RST (no 5->3v3 MAX809 ok->10Us VCC)
  SCK
  MISO
    Y->
   0.0           Y+                 0.400
    ----------------------------------
  X |                                |
  | |                                |
  V |                                |
    |                                |
  X+|                                |X-
    |                                |
    |                                |
    |                                |
    |                                |
    ----------------------------------
  240.0          Y-               240.400

  tft.setRotation(1)                             orientación pantalla, 1->horizontal, 0-> vertical
  tft.setCursor (x0,y0,)                         posiciona el cursor en las posición X0, Y0
  tft.print("texto")                             escribe el texto indicado
  tft.print(X, DEC)                              escribe el valor de las variable x en decimal
  tft.println                                    escribe el valor de las variable x en decimal + salto linea
  tft.setTextSize(3)                             tamaño del texto a 3,  1 = 5x8, 2 = 10x16 3 = 15x24
  tft.setTextColor(color)                        color del texto
  tft.setTextWrap(true)                          true-> sigue en la siguiente linea
  tft.fillScreen(color)                          borra la pantalla con el color indicado
  tft.fillRect (x0,y0, W6, H4, color)            rellena un recuadro de color del punto x0,y0 a con una anchura de 6 y una altura de 4
  tft.drawPixel(x0,y0, color)                    pinta el pixel indicado
  tft.drawFastHLine(x0,y0, L, color)             dibuja una línea horizontal de la longitud L
  tft.drawFastVLine(x0,y0, H, color)             dibuja una línea vertical de la longitud H
  tft.fillCircle(x, y, radio, color)             dibuja un circulo relleno
  tft.drawCircle(x, y, radio, color)             dibuja el contorno de un circulo
  tft.drawRect(X0, Y0, X1, Y1,color)             dibuja un rectángulo
  tft.width()                                    devuelve la anchura de la pantalla
  tft.height()                                   devuelve la altura de la pantalla
*/
#ifndef TFT_H
#define TFT_H

#include <Adafruit_GFX.h>                                             // Adafruit Core graphics library
#include <MCUFRIEND_kbv.h>                                            // TFTLCD LIBRARY MUST BE SPECIFICALLY FOR OPEN-SMART
#include <TouchScreen.h>                                              // https://github.com/adafruit/Adafruit_TouchScreen

// Colores usados:
#define BLACK   0x0000
#define BLUE    0x001F
#define RED     0xF800
#define GREEN   0x07E0
#define CYAN    0x07FF
#define MAGENTA 0xF81F
#define GREY    0xCCCC
#define ORANGE  0xFA60
#define YELLOW  0xFFE0
#define WHITE   0xFFFF

#define MINPRESION 100
#define MAXPRESION 1000

#define LCD_Ledk_pin 3

// modo retardo y pines para TouchScreen:
uint8_t YP = A1, XM = A2, YM = 7, XP = 6;

uint8_t ReposoMod = 1, ModoTrab = 0, BuzzerOnOFF = 1;
uint16_t tp_y = 500, tp_x = 500;                                      // memoria puntero

MCUFRIEND_kbv tft;
// la resistencia medida entre X+ y X- es de 304 ohms
TouchScreen ts = TouchScreen(XP, YP, XM, YM, 304);                    // instancia ts para  touchscreen
TSPoint tp;
LM75 sensor;                                                          // el sensor se encuentra en la PCB del LCD

//********************************************************************************************
// Delay 16000 ciclos * 62,5 ns->1ms para oscilador de 16.0 MHz
//--------------------------------------------------------------------------------------------
void DelayMs(uint16_t Ms) {
  do {
    asm volatile (                                                    // 15994 ciclos
      "    ldi  r18, 21"  "\n"                                        // 1 ciclo, carga el registro r18 con el valor 21
      "    ldi  r19, 197" "\n"                                        // 1 ciclo, carga el registro r19 con el valor 197
      "1:  dec  r19"  "\n"                                            // 1 ciclo, decrementamos r19 en 1
      "    brne 1b" "\n"                                              // 2 ciclos, si 1b!=0 salta a 1
      "    dec  r18"  "\n"                                            // 1 ciclo, decrementamos r18 en 1
      "    brne 1b" "\n"                                              // 2 ciclos, si 1b!=0 salta a 1
    );
  } while (--Ms != 0);                                                // +6 ciclos
}
//********************************************************************************************
// Dibuja el mapa de bits de la imagen indicada
//--------------------------------------------------------------------------------------------
void BitMap (uint8_t x) {
  switch (x) {
    case 1:
      tft.drawRGBBitmap(15, 25, lm75, 48, 48);                        // imagen temperatura PCB
      break;
    case 2:
      tft.drawRGBBitmap(110, 180, drec, 64, 64);                      // imagen decremento
      break;
    case 3:
      tft.drawRGBBitmap(230, 180, incr, 64, 64);                      // imagen incremento
      break;
    case 4:
      tft.drawRGBBitmap(330, 10, config, 48, 48);                     // imagen configuración
      break;
    case 5:
      tft.drawRGBBitmap(330, 70, mem, 48, 48);                        // imagen memoria
      tft.drawRGBBitmap(330, 125, mem, 48, 48);                       // imagen memoria
      tft.drawRGBBitmap(330, 180, mem, 48, 48);                       // imagen memoria
      break;
    case 6:
      tft.drawRGBBitmap(10, 90, sleep, 48, 48);                       // imagen reposo
      break;
    case 7:
      tft.drawRGBBitmap(5, 175, on, 64, 64);                          // imagen ON
      break;
    case 8:
      tft.drawRGBBitmap(5, 175, off, 64, 64);                         // imagen OFF
      break;
  }
}
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

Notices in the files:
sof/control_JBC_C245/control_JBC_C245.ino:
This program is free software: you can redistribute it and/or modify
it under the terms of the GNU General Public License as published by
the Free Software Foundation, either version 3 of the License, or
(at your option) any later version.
